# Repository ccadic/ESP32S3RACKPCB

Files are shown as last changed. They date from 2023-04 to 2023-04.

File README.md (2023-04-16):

# ESP32S3RACKPCB
This is a 1U rack PCB to hold 8 x ESP32S3 Wroom chips.

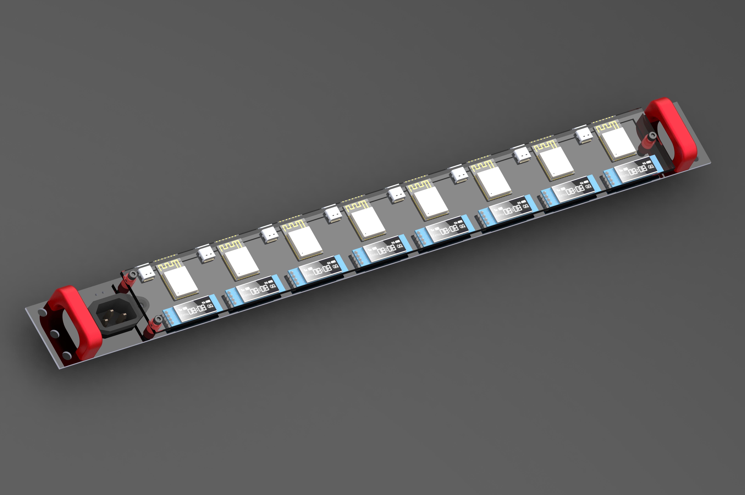
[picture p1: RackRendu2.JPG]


You have the STEP file, solidworks files, Kicad files and gerbers
@sulfuroid

My USDT address: 0xA7Cb711124e1Be5cad35aABB5d8a29b6dfdfc594 for coffees...

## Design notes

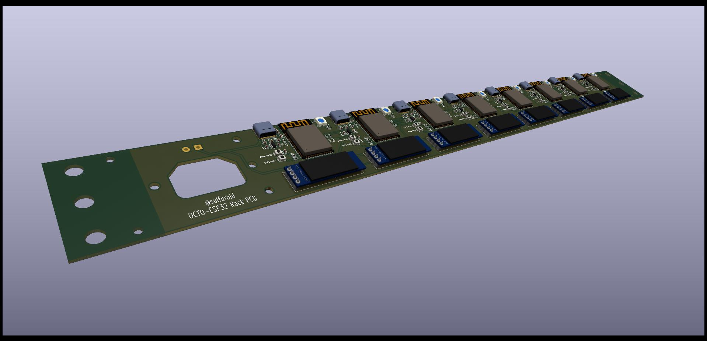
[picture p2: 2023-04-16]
RACK-ESP32S2.jpg

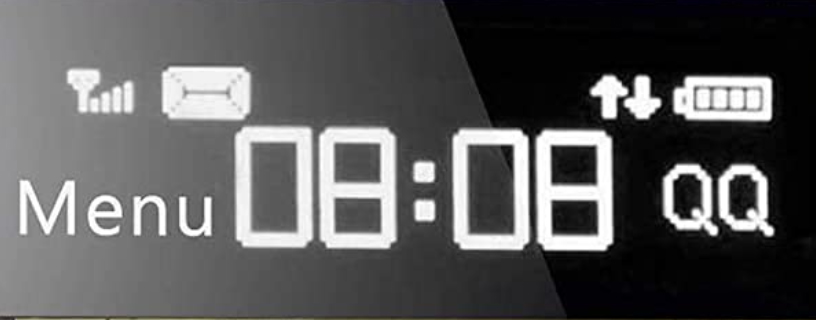
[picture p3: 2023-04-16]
displayoled.jpg

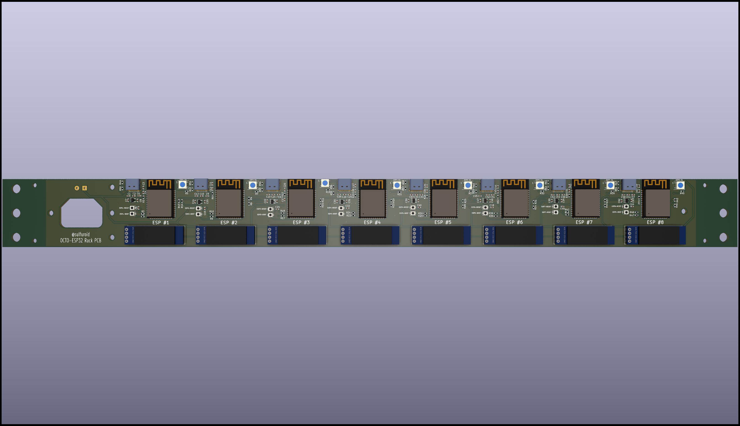
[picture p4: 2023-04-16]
RACK-ESP32S3.jpg

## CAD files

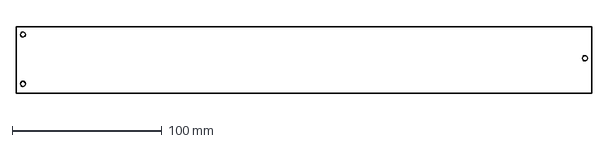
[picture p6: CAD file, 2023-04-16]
stlfiles/acrylic_front_protection.DXF
385.0 x 44.6 mm

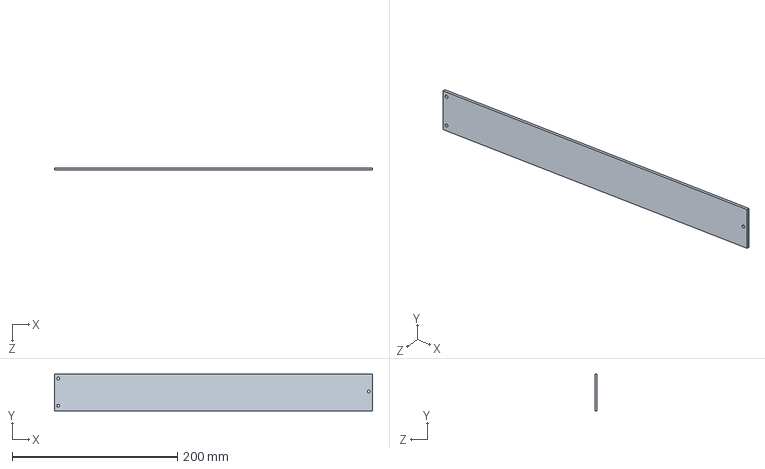
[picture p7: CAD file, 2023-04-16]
vitre.SLDPRT
385.0 x 44.6 x 3.00 mm

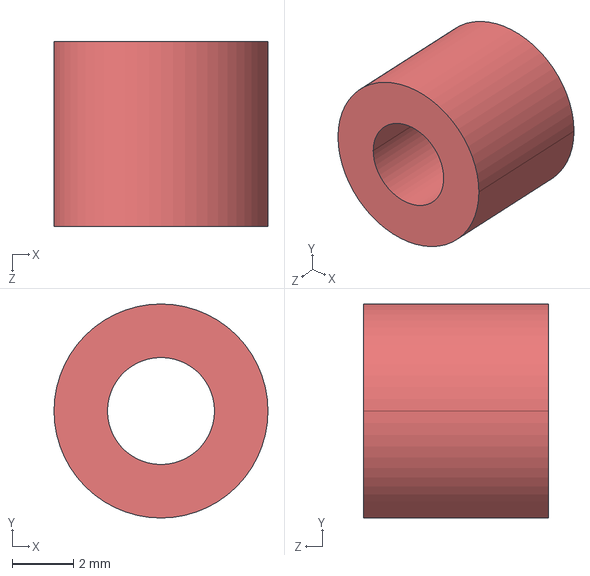
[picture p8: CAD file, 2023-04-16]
stlfiles/spacers.STEP
7.00 x 7.00 x 6.05 mm

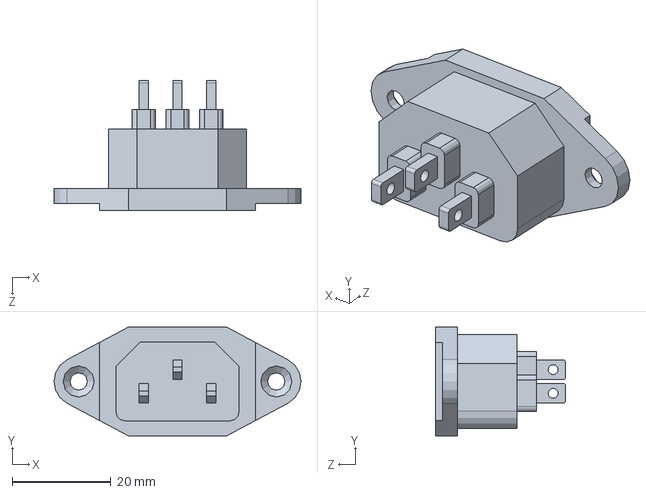
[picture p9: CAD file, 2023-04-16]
IEC-C4-3pins.SLDPRT
50.0 x 22.0 x 26.4 mm

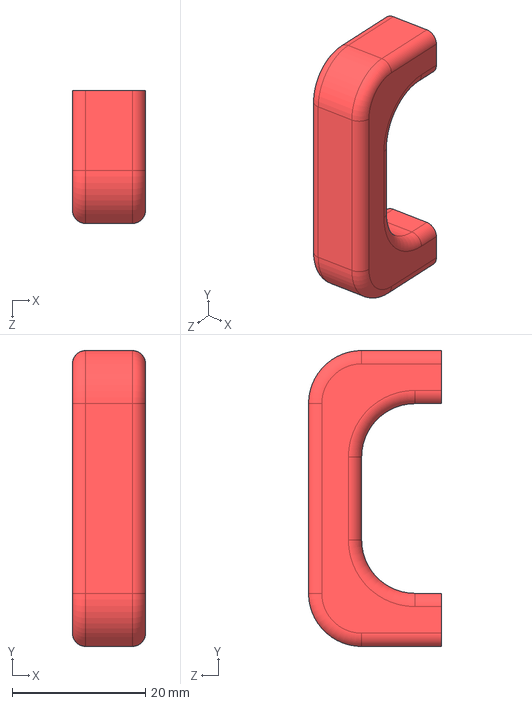
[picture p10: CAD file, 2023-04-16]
stlfiles/poignee.STEP
11.0 x 44.5 x 20.0 mm

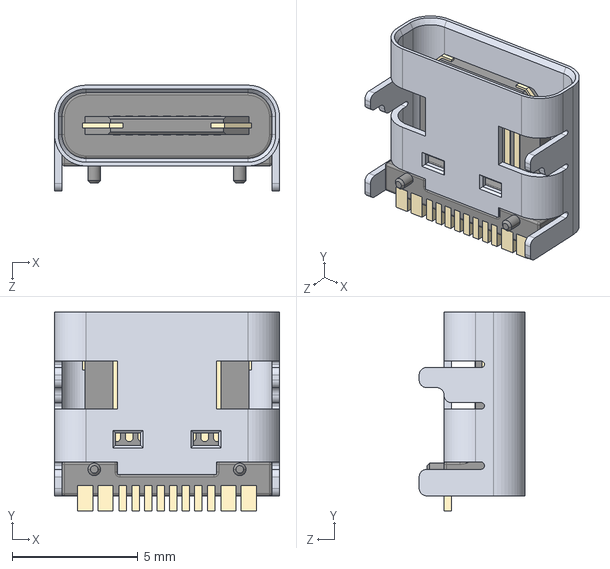
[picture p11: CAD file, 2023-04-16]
USB Type C Port (SMD Type).STEP
8.94 x 7.90 x 4.20 mm

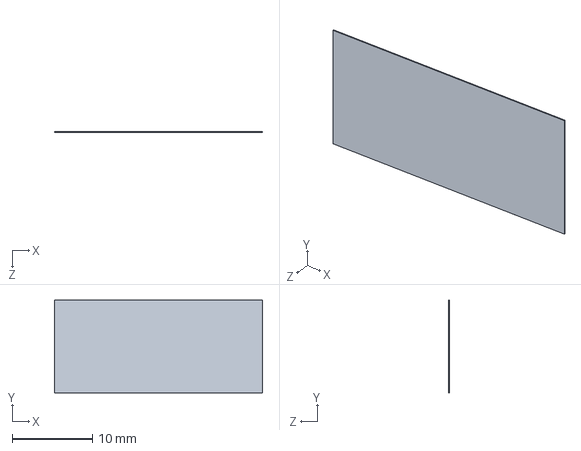
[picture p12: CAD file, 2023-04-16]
oleddisplay.SLDPRT
26.0 x 11.6 x 0.1 mm

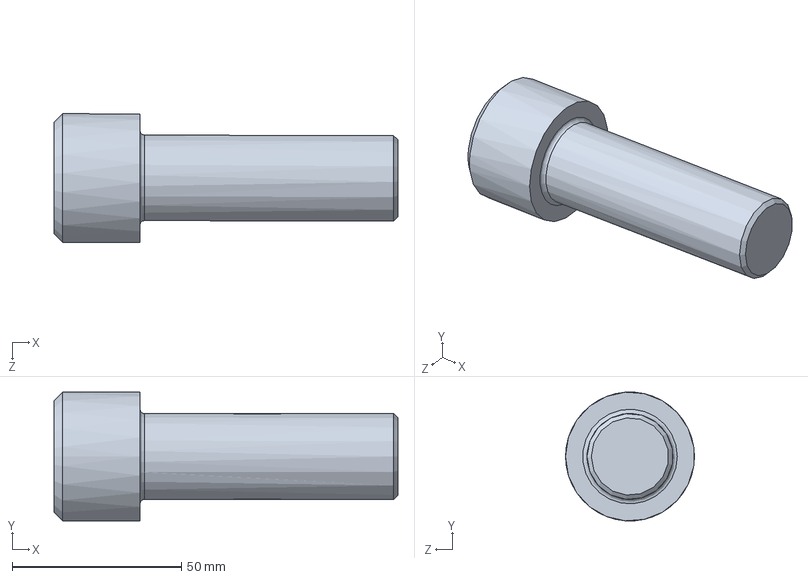
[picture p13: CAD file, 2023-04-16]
socket head cap screw_ai.SLDPRT
101.6 x 38.0 x 38.1 mm

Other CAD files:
poignee.SLDPRT
spacers.SLDPRT
stlfiles/poignee.STL
stlfiles/spacers.STL

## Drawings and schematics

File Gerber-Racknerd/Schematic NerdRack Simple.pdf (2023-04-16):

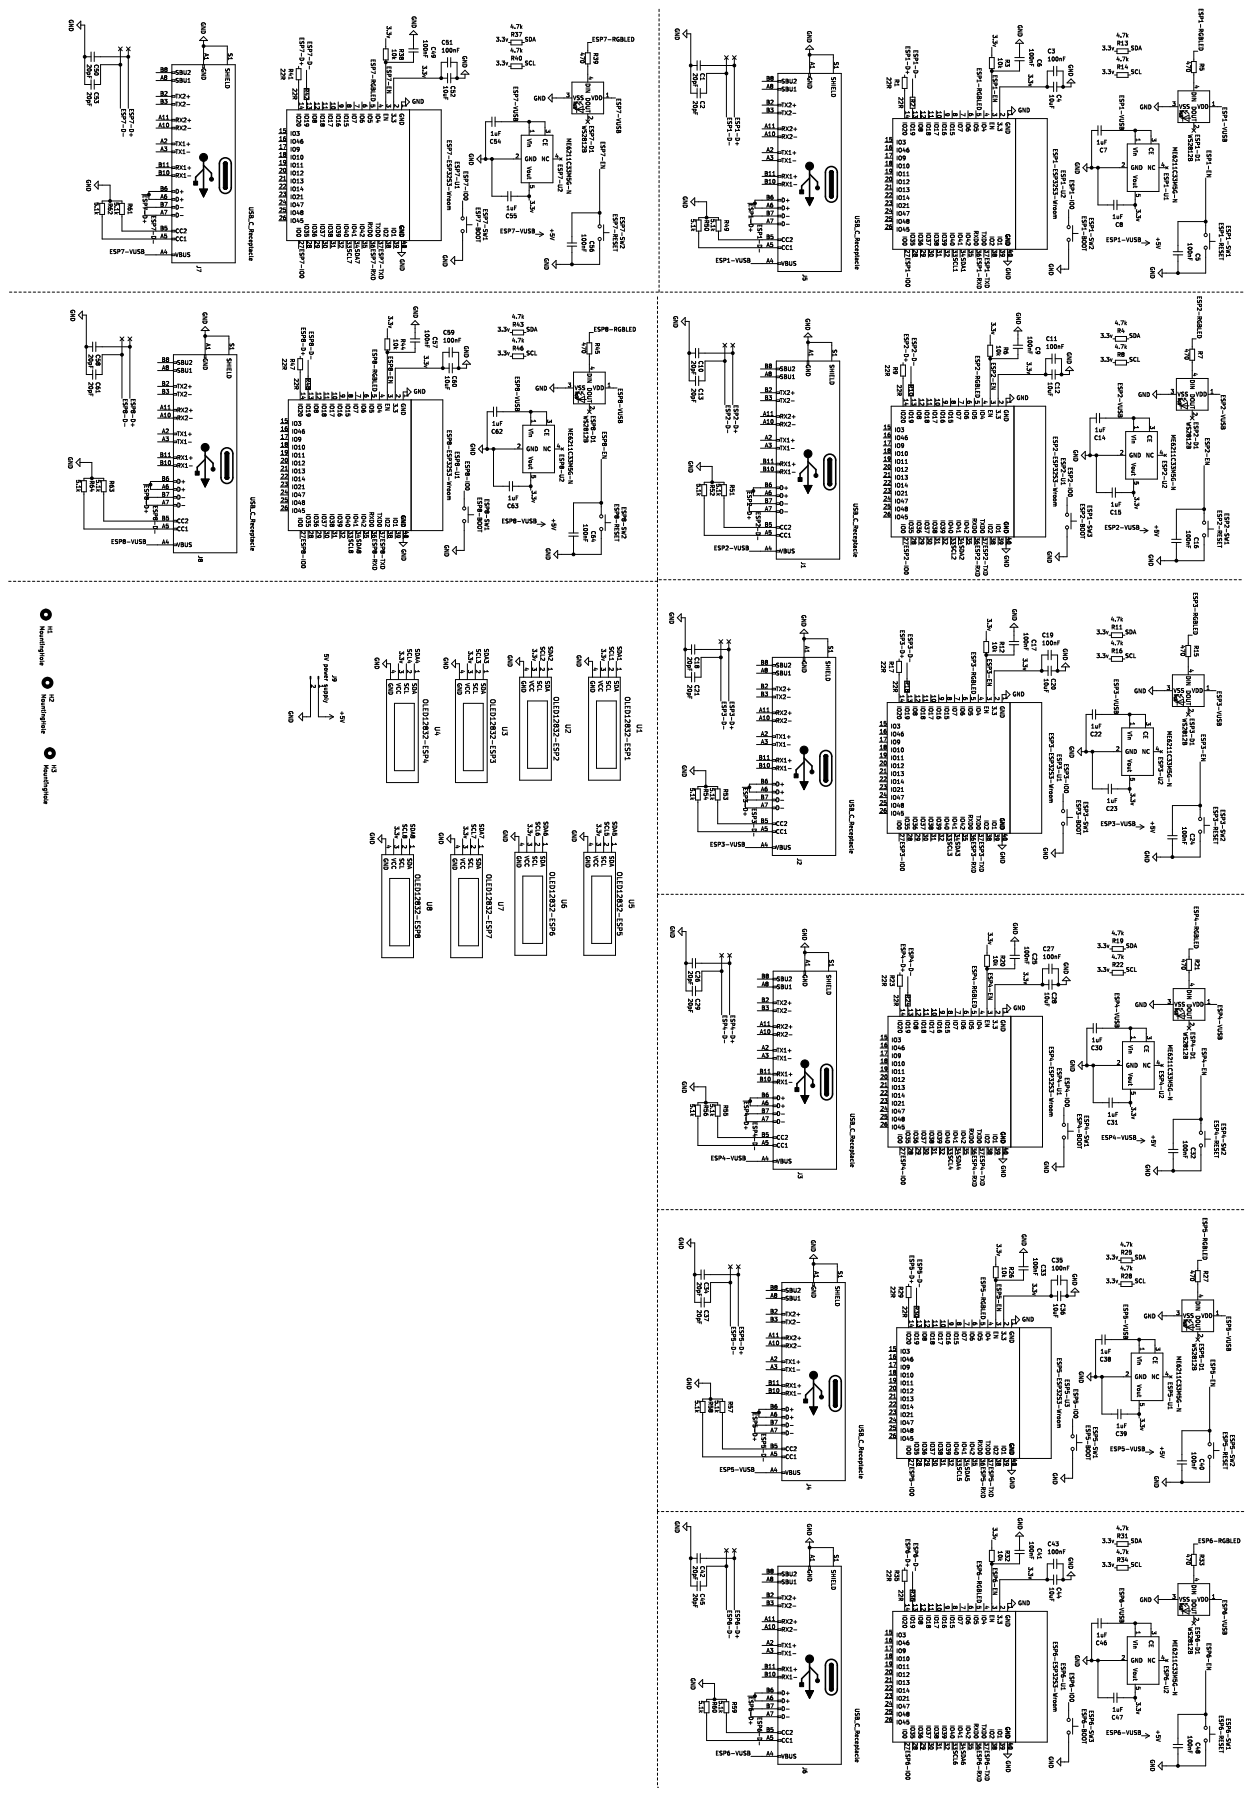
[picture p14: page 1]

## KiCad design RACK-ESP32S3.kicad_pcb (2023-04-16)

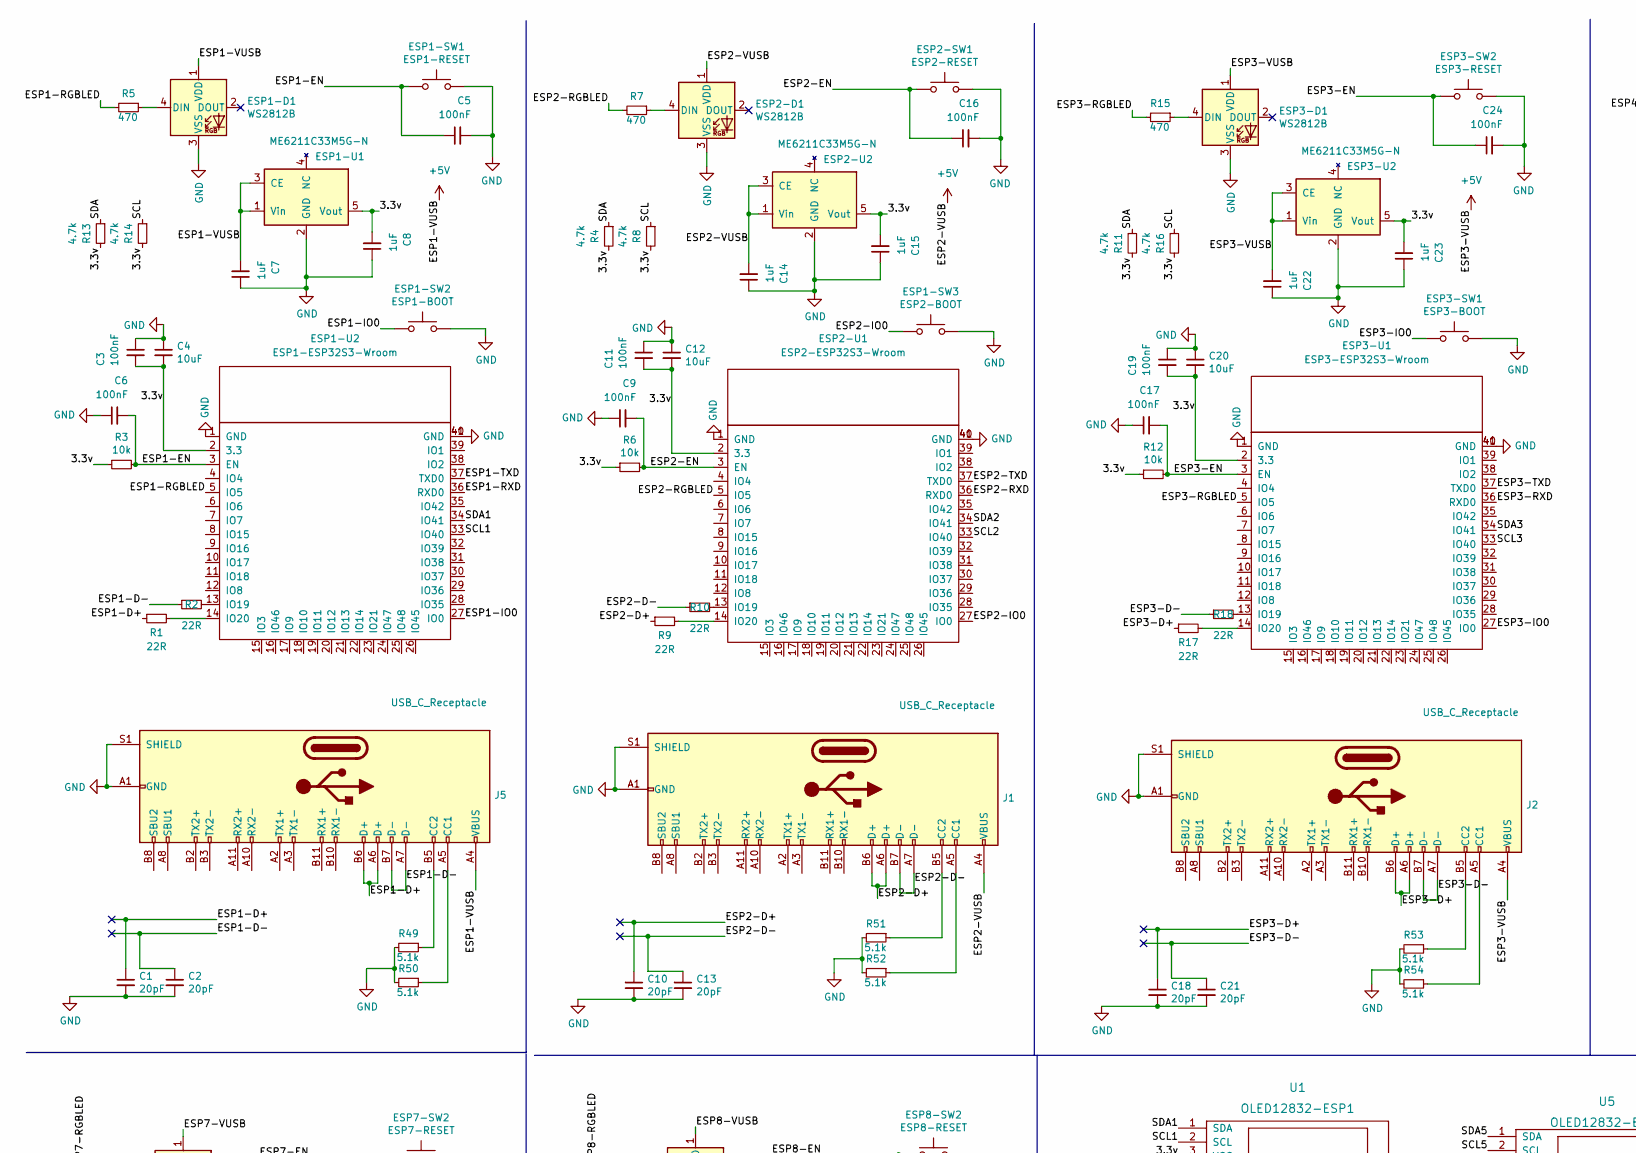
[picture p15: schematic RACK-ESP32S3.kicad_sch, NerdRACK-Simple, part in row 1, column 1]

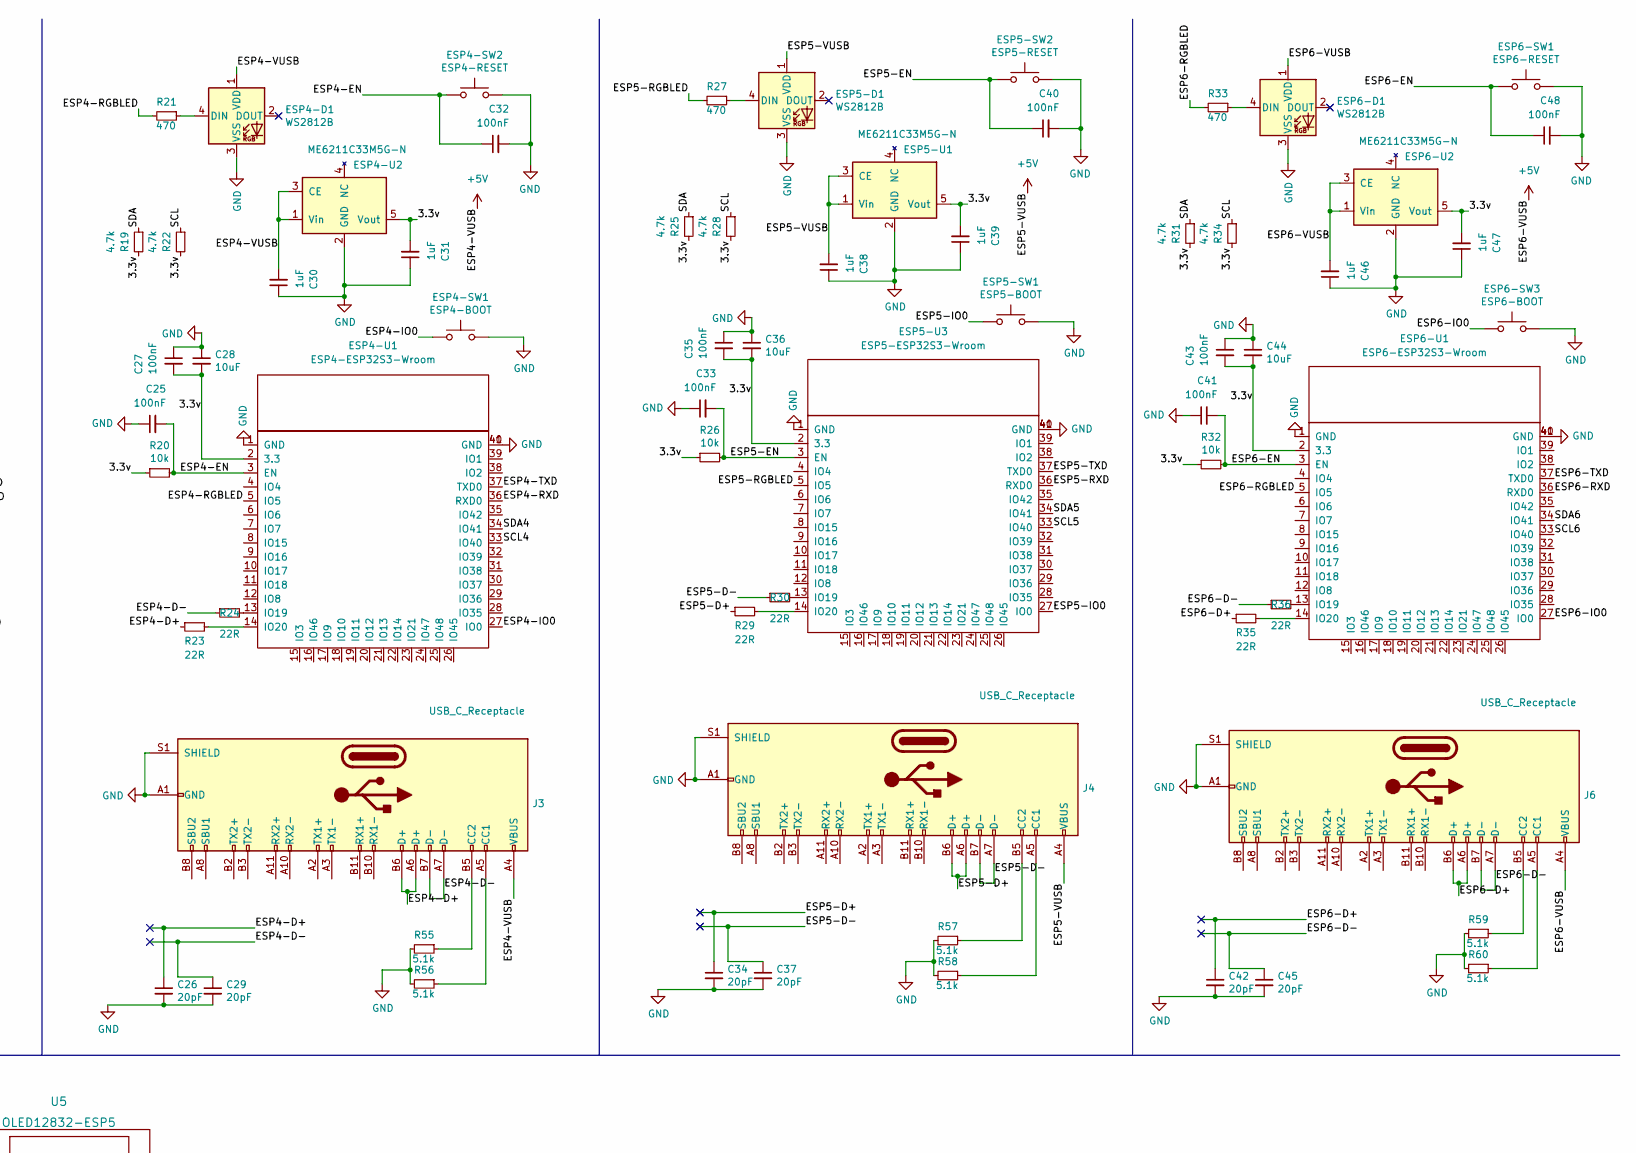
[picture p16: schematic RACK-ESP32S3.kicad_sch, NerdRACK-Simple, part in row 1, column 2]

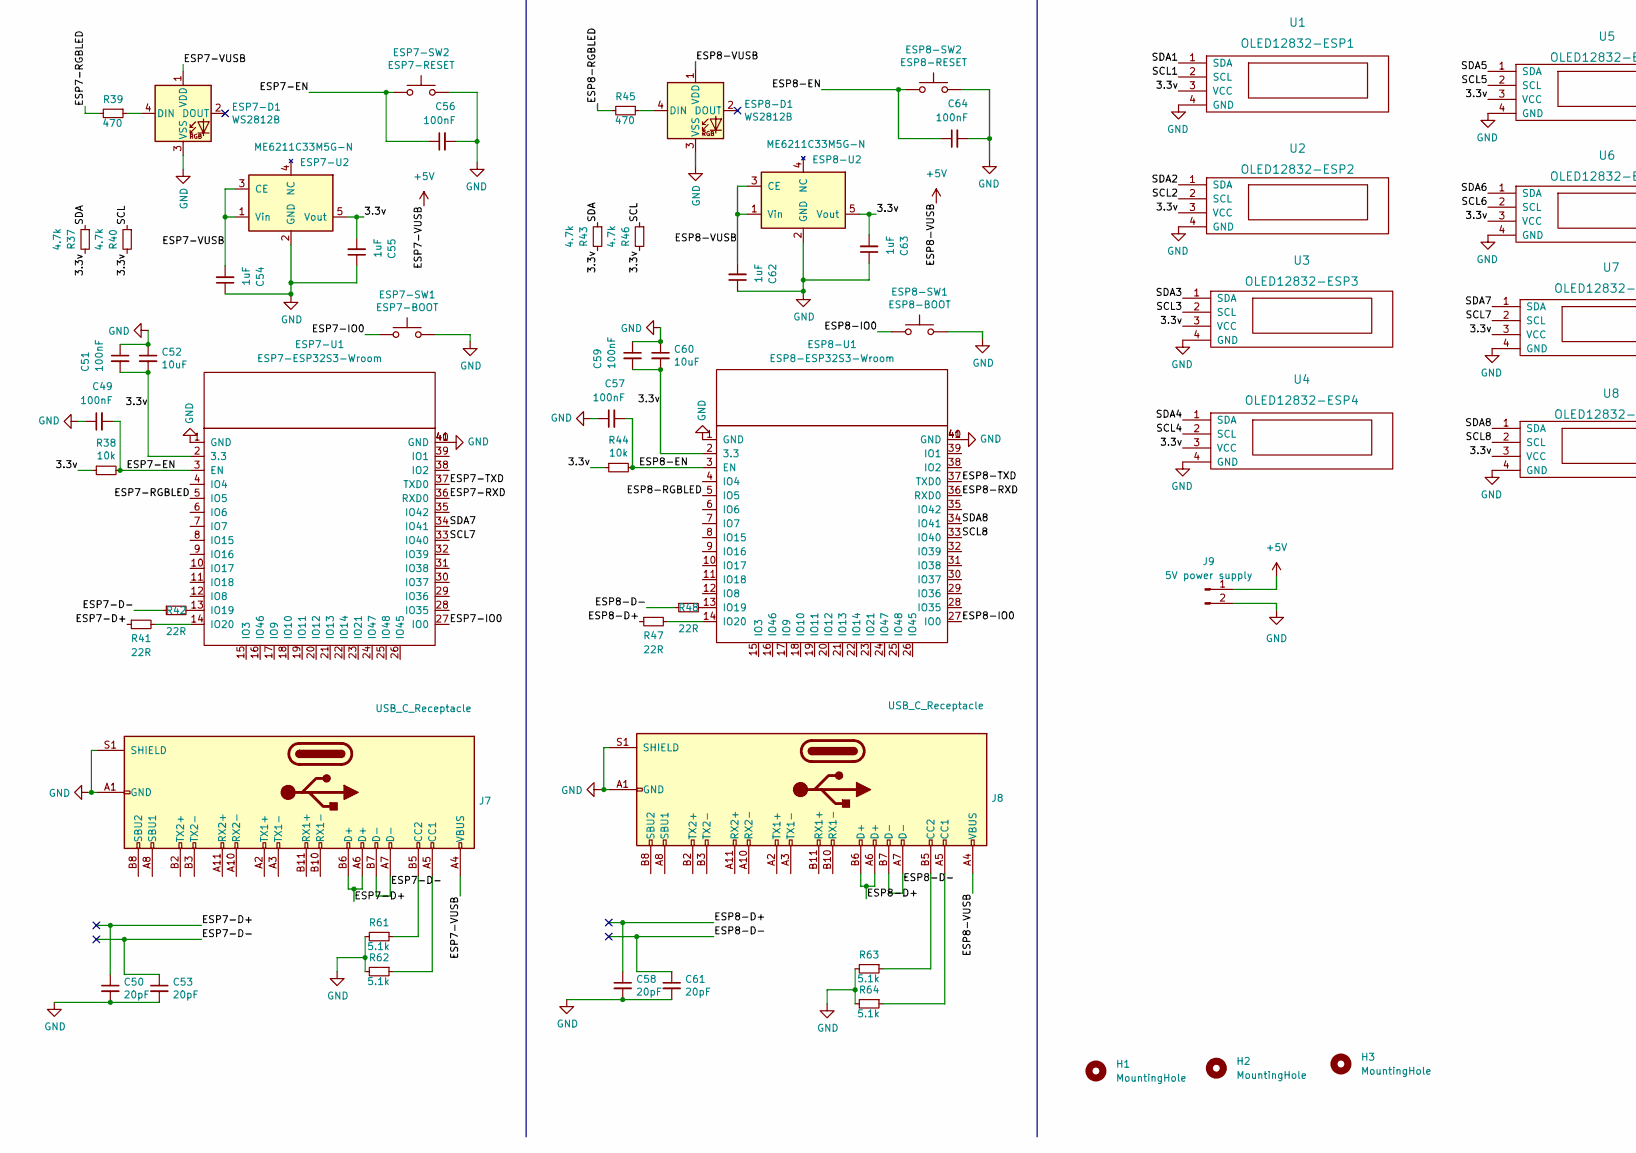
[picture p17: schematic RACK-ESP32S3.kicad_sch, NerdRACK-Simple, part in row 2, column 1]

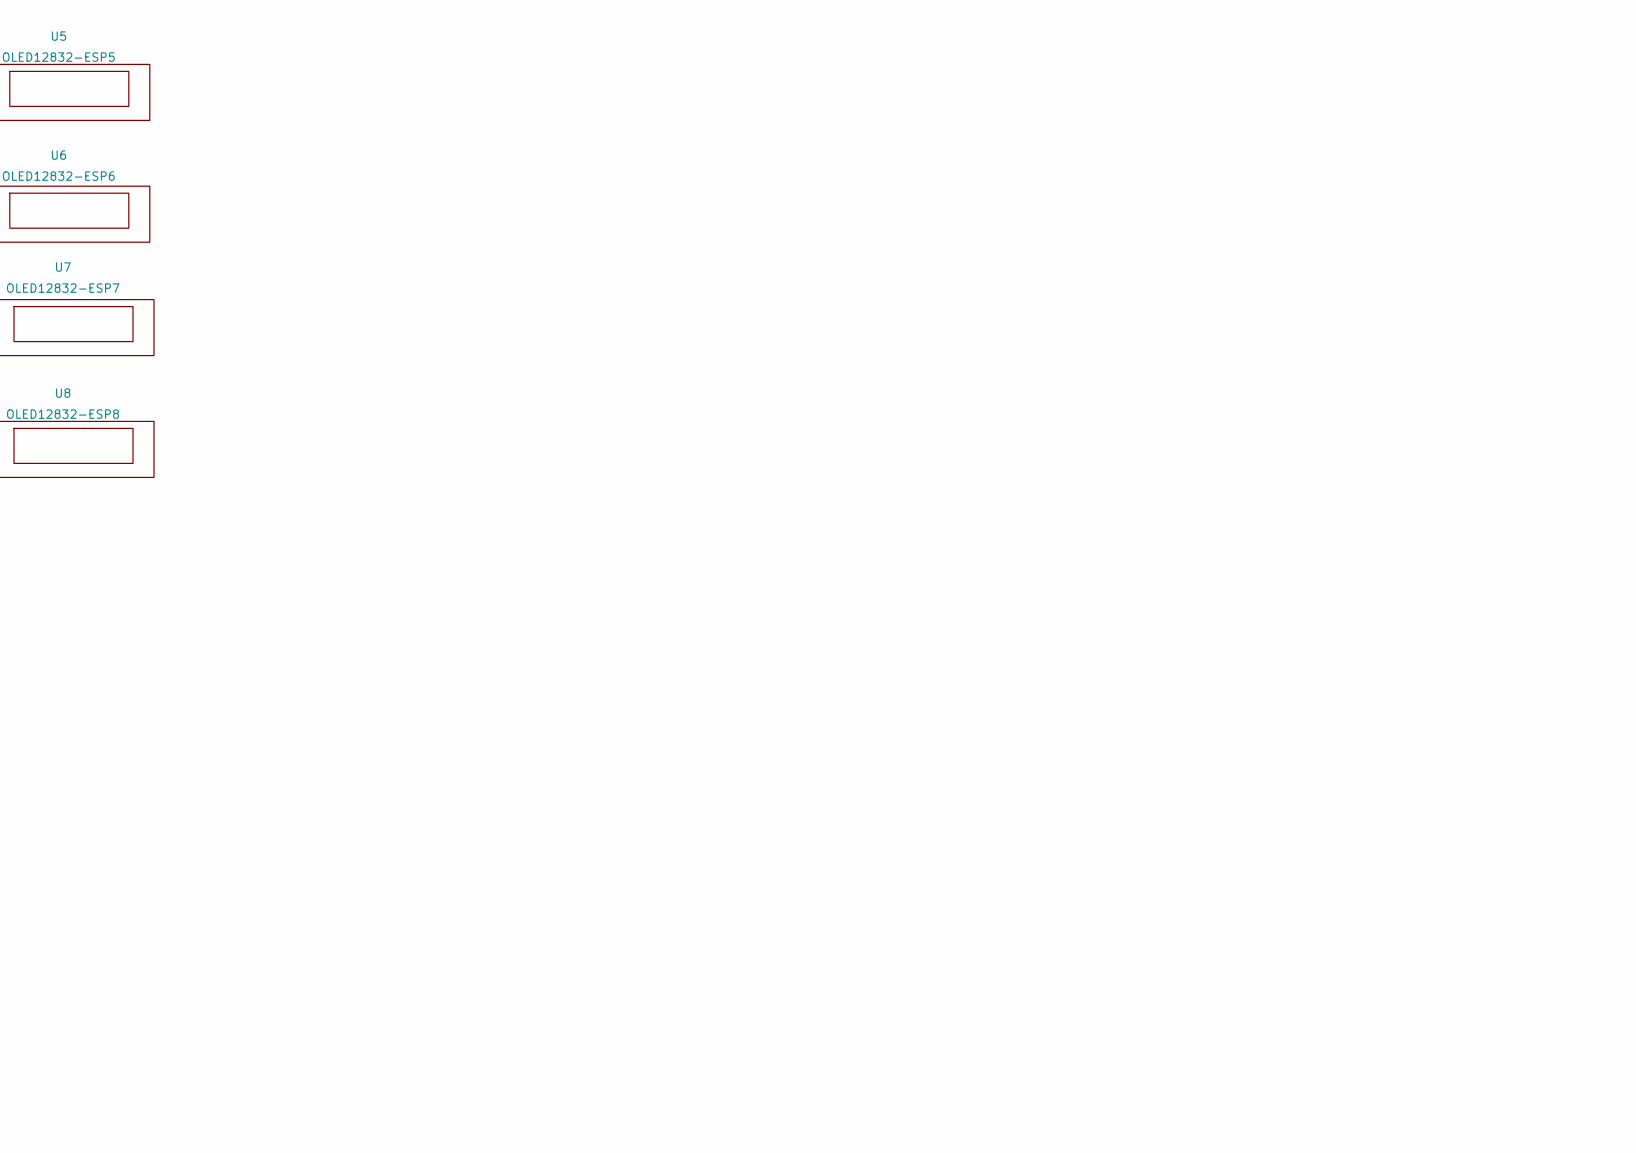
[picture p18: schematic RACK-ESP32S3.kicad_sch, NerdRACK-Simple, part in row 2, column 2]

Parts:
C1, C2, C10, C13, C18, C21, C26, C29, C34, C37, C42, C45, C50, C53, C58, C61: 20pF; C_0603_1608Metric
C3, C5, C6, C9, C11, C16, C17, C19, C24, C25, C27, C32, C33, C35, C40, C41, C43, C48, C49, C51, C56, C57, C59, C64: 100nF; C_0603_1608Metric
C4, C12, C20, C28, C36, C44, C52, C60: 10uF; C_0603_1608Metric
C7, C8, C14, C15, C22, C23, C30, C31, C38, C39, C46, C47, C54, C55, C62, C63: 1uF; C_0603_1608Metric
ESP1-D1, ESP2-D1, ESP3-D1, ESP4-D1, ESP5-D1, ESP6-D1, ESP7-D1, ESP8-D1: WS2812B; LED_WS2812B_PLCC4_5.0x5.0mm_P3.2mm
ESP1-SW1: ESP1-RESET; SW_SPST_B3U-1000P
ESP1-SW2: ESP1-BOOT; SW_SPST_B3U-1000P
ESP1-SW3: ESP2-BOOT; SW_SPST_B3U-1000P
ESP1-U1, ESP2-U2, ESP3-U2, ESP4-U2, ESP5-U1, ESP6-U2, ESP7-U2, ESP8-U2: ME6211C33M5G-N; SOT-23-5
ESP1-U2: ESP1-ESP32S3-Wroom; ESP32-S3-WROOM-1
ESP2-SW1: ESP2-RESET; SW_SPST_B3U-1000P
ESP2-U1: ESP2-ESP32S3-Wroom; ESP32-S3-WROOM-1
ESP3-SW1: ESP3-BOOT; SW_SPST_B3U-1000P
ESP3-SW2: ESP3-RESET; SW_SPST_B3U-1000P
ESP3-U1: ESP3-ESP32S3-Wroom; ESP32-S3-WROOM-1
ESP4-SW1: ESP4-BOOT; SW_SPST_B3U-1000P
ESP4-SW2: ESP4-RESET; SW_SPST_B3U-1000P
ESP4-U1: ESP4-ESP32S3-Wroom; ESP32-S3-WROOM-1
ESP5-SW1: ESP5-BOOT; SW_SPST_B3U-1000P
ESP5-SW2: ESP5-RESET; SW_SPST_B3U-1000P
ESP5-U3: ESP5-ESP32S3-Wroom; ESP32-S3-WROOM-1
ESP6-SW1: ESP6-RESET; SW_SPST_B3U-1000P
ESP6-SW3: ESP6-BOOT; SW_SPST_B3U-1000P
ESP6-U1: ESP6-ESP32S3-Wroom; ESP32-S3-WROOM-1
ESP7-SW1: ESP7-BOOT; SW_SPST_B3U-1000P
ESP7-SW2: ESP7-RESET; SW_SPST_B3U-1000P
ESP7-U1: ESP7-ESP32S3-Wroom; ESP32-S3-WROOM-1
ESP8-SW1: ESP8-BOOT; SW_SPST_B3U-1000P
ESP8-SW2: ESP8-RESET; SW_SPST_B3U-1000P
ESP8-U1: ESP8-ESP32S3-Wroom; ESP32-S3-WROOM-1
H1, H2, H3: MountingHole; MountingHole_3.5mm
J1, J2, J3, J4, J5, J6, J7, J8: USB_C_Receptacle; GT-USB-7010
J9: 5V power supply; TerminalBlock_bornier-2_P5.08mm
R1, R2, R9, R10, R17, R18, R23, R24, R29, R30, R35, R36, R41, R42, R47, R48: 22R; R_0603_1608Metric
R3, R6, R12, R20, R26, R32, R38, R44: 10k; R_0603_1608Metric
R4, R8, R11, R13, R14, R16, R19, R22, R25, R28, R31, R34, R37, R40, R43, R46: 4.7k; R_0603_1608Metric
R5, R7, R15, R21, R27, R33, R39, R45: 470; R_0603_1608Metric
R49, R50, R51, R52, R53, R54, R55, R56, R57, R58, R59, R60, R61, R62, R63, R64: 5.1k; R_0603_1608Metric
U1: OLED12832-ESP1; OLED-0.91-128x32
U2: OLED12832-ESP2; OLED-0.91-128x32
U3: OLED12832-ESP3; OLED-0.91-128x32
U4: OLED12832-ESP4; OLED-0.91-128x32
U5: OLED12832-ESP5; OLED-0.91-128x32
U6: OLED12832-ESP6; OLED-0.91-128x32
U7: OLED12832-ESP7; OLED-0.91-128x32
U8: OLED12832-ESP8; OLED-0.91-128x32

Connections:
+5V: C7.2, C14.2, C22.2, C30.2, C38.2, C46.2, C54.2, C62.2, ESP1-D1.1 (VDD), ESP1-U1.1 (Vin), ESP1-U1.3 (CE), ESP2-D1.1 (VDD), ESP2-U2.1 (Vin), ESP2-U2.3 (CE), ESP3-D1.1 (VDD), ESP3-U2.1 (Vin), ESP3-U2.3 (CE), ESP4-D1.1 (VDD), ESP4-U2.1 (Vin), ESP4-U2.3 (CE), ESP5-D1.1 (VDD), ESP5-U1.1 (Vin), ESP5-U1.3 (CE), ESP6-D1.1 (VDD), ESP6-U2.1 (Vin), ESP6-U2.3 (CE), ESP7-D1.1 (VDD), ESP7-U2.1 (Vin), ESP7-U2.3 (CE), ESP8-D1.1 (VDD), ESP8-U2.1 (Vin), ESP8-U2.3 (CE), J1.A4 (VBUS), J1.A9 (VBUS), J1.B4 (VBUS), J1.B9 (VBUS), J2.A4 (VBUS), J2.A9 (VBUS), J2.B4 (VBUS), J2.B9 (VBUS), J3.A4 (VBUS), J3.A9 (VBUS), J3.B4 (VBUS), J3.B9 (VBUS), J4.A4 (VBUS), J4.A9 (VBUS), J4.B4 (VBUS), J4.B9 (VBUS), J5.A4 (VBUS), J5.A9 (VBUS), J5.B4 (VBUS), J5.B9 (VBUS), J6.A4 (VBUS), J6.A9 (VBUS), J6.B4 (VBUS), J6.B9 (VBUS), J7.A4 (VBUS), J7.A9 (VBUS), J7.B4 (VBUS), J7.B9 (VBUS), J8.A4 (VBUS), J8.A9 (VBUS), J8.B4 (VBUS), J8.B9 (VBUS), J9.1
/3.3v: C3.2, C4.2, C8.2, C11.2, C12.2, C15.2, C19.2, C20.2, C23.2, C27.2, C28.2, C31.2, C35.2, C36.2, C39.2, C43.2, C44.2, C47.2, C51.2, C52.2, C55.2, C59.2, C60.2, C63.2, ESP1-U1.5 (Vout), ESP1-U2.2 (3.3), ESP2-U1.2 (3.3), ESP2-U2.5 (Vout), ESP3-U1.2 (3.3), ESP3-U2.5 (Vout), ESP4-U1.2 (3.3), ESP4-U2.5 (Vout), ESP5-U1.5 (Vout), ESP5-U3.2 (3.3), ESP6-U1.2 (3.3), ESP6-U2.5 (Vout), ESP7-U1.2 (3.3), ESP7-U2.5 (Vout), ESP8-U1.2 (3.3), ESP8-U2.5 (Vout), R3.1, R4.2, R6.1, R8.2, R11.2, R12.1, R13.2, R14.2, R16.2, R19.2, R20.1, R22.2, R25.2, R26.1, R28.2, R31.2, R32.1, R34.2, R37.2, R38.1, R40.2, R43.2, R44.1, R46.2, U1.3 (VCC), U2.3 (VCC), U3.3 (VCC), U4.3 (VCC), U5.3 (VCC), U6.3 (VCC), U7.3 (VCC), U8.3 (VCC); also elsewhere on the board
/ESP1-D+: C1.1, J5.A6 (D+), J5.B6 (D+), R1.1
/ESP1-D-: C2.1, J5.A7 (D-), J5.B7 (D-), R2.1
/ESP1-EN: C5.1, C6.2, ESP1-SW1.2, ESP1-U2.3 (EN), R3.2
/ESP1-IO0: ESP1-SW2.1, ESP1-U2.27 (IO0)
/ESP1-RGBLED: ESP1-U2.5 (IO5), R5.2
/ESP1-RXD: ESP1-U2.36 (RXD0)
/ESP1-TXD: ESP1-U2.37 (TXD0)
/ESP2-D+: C10.1, J1.A6 (D+), J1.B6 (D+), R9.1
/ESP2-D-: C13.1, J1.A7 (D-), J1.B7 (D-), R10.1
/ESP2-EN: C9.2, C16.1, ESP2-SW1.2, ESP2-U1.3 (EN), R6.2
/ESP2-IO0: ESP1-SW3.1, ESP2-U1.27 (IO0)
/ESP2-RGBLED: ESP2-U1.5 (IO5), R7.2
/ESP2-RXD: ESP2-U1.36 (RXD0)
/ESP2-TXD: ESP2-U1.37 (TXD0)
/ESP3-D+: C18.1, J2.A6 (D+), J2.B6 (D+), R17.1
/ESP3-D-: C21.1, J2.A7 (D-), J2.B7 (D-), R18.1
/ESP3-EN: C17.2, C24.1, ESP3-SW2.2, ESP3-U1.3 (EN), R12.2
/ESP3-IO0: ESP3-SW1.1, ESP3-U1.27 (IO0)
/ESP3-RGBLED: ESP3-U1.5 (IO5), R15.2
/ESP3-RXD: ESP3-U1.36 (RXD0)
/ESP3-TXD: ESP3-U1.37 (TXD0)
/ESP4-D+: C26.1, J3.A6 (D+), J3.B6 (D+), R23.1
/ESP4-D-: C29.1, J3.A7 (D-), J3.B7 (D-), R24.1
/ESP4-EN: C25.2, C32.1, ESP4-SW2.2, ESP4-U1.3 (EN), R20.2
/ESP4-IO0: ESP4-SW1.1, ESP4-U1.27 (IO0)
/ESP4-RGBLED: ESP4-U1.5 (IO5), R21.2
/ESP4-RXD: ESP4-U1.36 (RXD0)
/ESP4-TXD: ESP4-U1.37 (TXD0)
/ESP5-D+: C34.1, J4.A6 (D+), J4.B6 (D+), R29.1
/ESP5-D-: C37.1, J4.A7 (D-), J4.B7 (D-), R30.1
/ESP5-EN: C33.2, C40.1, ESP5-SW2.2, ESP5-U3.3 (EN), R26.2
/ESP5-IO0: ESP5-SW1.1, ESP5-U3.27 (IO0)
/ESP5-RGBLED: ESP5-U3.5 (IO5), R27.2
/ESP5-RXD: ESP5-U3.36 (RXD0)
/ESP5-TXD: ESP5-U3.37 (TXD0)
/ESP6-D+: C42.1, J6.A6 (D+), J6.B6 (D+), R35.1
/ESP6-D-: C45.1, J6.A7 (D-), J6.B7 (D-), R36.1
/ESP6-EN: C41.2, C48.1, ESP6-SW1.2, ESP6-U1.3 (EN), R32.2; also elsewhere on the board
/ESP6-IO0: ESP6-SW3.1, ESP6-U1.27 (IO0); also elsewhere on the board
/ESP6-RGBLED: ESP6-U1.5 (IO5), R33.2; also elsewhere on the board
/ESP7-D+: C50.1, J7.A6 (D+), J7.B6 (D+), R41.1
/ESP7-D-: C53.1, J7.A7 (D-), J7.B7 (D-), R42.1
/ESP7-EN: C49.2, C56.1, ESP7-SW2.2, ESP7-U1.3 (EN), R38.2
/ESP7-IO0: ESP7-SW1.1, ESP7-U1.27 (IO0)
/ESP7-RGBLED: ESP7-U1.5 (IO5), R39.2
/ESP7-RXD: ESP7-U1.36 (RXD0)
/ESP7-TXD: ESP7-U1.37 (TXD0)
/ESP8-D+: C58.1, J8.A6 (D+), J8.B6 (D+), R47.1
/ESP8-D-: C61.1, J8.A7 (D-), J8.B7 (D-), R48.1
/ESP8-EN: C57.2, C64.1, ESP8-SW2.2, ESP8-U1.3 (EN), R44.2
/ESP8-IO0: ESP8-SW1.1, ESP8-U1.27 (IO0)
/ESP8-RGBLED: ESP8-U1.5 (IO5), R45.2
/ESP8-RXD: ESP8-U1.36 (RXD0)
/ESP8-TXD: ESP8-U1.37 (TXD0)
/SCL: R8.1, R14.1, R16.1, R22.1, R28.1, R34.1, R40.1, R46.1
/SCL1: ESP1-U2.33 (IO40), U1.2 (SCL)
/SCL2: ESP2-U1.33 (IO40), U2.2 (SCL)
/SCL3: ESP3-U1.33 (IO40), U3.2 (SCL)
/SCL4: ESP4-U1.33 (IO40), U4.2 (SCL)
/SCL5: ESP5-U3.33 (IO40), U5.2 (SCL)
/SCL6: ESP6-U1.33 (IO40), U6.2 (SCL); also elsewhere on the board
/SCL7: ESP7-U1.33 (IO40), U7.2 (SCL)
/SCL8: ESP8-U1.33 (IO40), U8.2 (SCL)
/SDA: R4.1, R11.1, R13.1, R19.1, R25.1, R31.1, R37.1, R43.1
/SDA1: ESP1-U2.34 (IO41), U1.1 (SDA)
/SDA2: ESP2-U1.34 (IO41), U2.1 (SDA)
/SDA3: ESP3-U1.34 (IO41), U3.1 (SDA)
/SDA4: ESP4-U1.34 (IO41), U4.1 (SDA)
/SDA5: ESP5-U3.34 (IO41), U5.1 (SDA)
/SDA6: ESP6-U1.34 (IO41), U6.1 (SDA); also elsewhere on the board
/SDA7: ESP7-U1.34 (IO41), U7.1 (SDA)
/SDA8: ESP8-U1.34 (IO41), U8.1 (SDA)
GND: C1.2, C2.2, C3.1, C4.1, C5.2, C6.1, C7.1, C8.1, C9.1, C10.2, C11.1, C12.1, C13.2, C14.1, C15.1, C16.2, C17.1, C18.2, C19.1, C20.1, C21.2, C22.1, C23.1, C24.2, C25.1, C26.2, C27.1, C28.1, C29.2, C30.1, C31.1, C32.2, C33.1, C34.2, C35.1, C36.1, C37.2, C38.1, C39.1, C40.2, C41.1, C42.2, C43.1, C44.1, C45.2, C46.1, C47.1, C48.2, C49.1, C50.2, C51.1, C52.1, C53.2, C54.1, C55.1, C56.2, C57.1, C58.2, C59.1, C60.1, C61.2, C62.1, C63.1, C64.2, ESP1-D1.3 (VSS), ESP1-SW1.1, ESP1-SW2.2, ESP1-SW3.2, ESP1-U1.2 (GND), ESP1-U2.1 (GND), ESP1-U2.40 (GND), ESP1-U2.41 (GND), ESP2-D1.3 (VSS), ESP2-SW1.1, ESP2-U1.1 (GND), ESP2-U1.40 (GND), ESP2-U1.41 (GND), ESP2-U2.2 (GND), ESP3-D1.3 (VSS), ESP3-SW1.2, ESP3-SW2.1, ESP3-U1.1 (GND), ESP3-U1.40 (GND), ESP3-U1.41 (GND), ESP3-U2.2 (GND), ESP4-D1.3 (VSS), ESP4-SW1.2, ESP4-SW2.1, ESP4-U1.1 (GND), ESP4-U1.40 (GND), ESP4-U1.41 (GND), ESP4-U2.2 (GND), ESP5-D1.3 (VSS), ESP5-SW1.2, ESP5-SW2.1, ESP5-U1.2 (GND), ESP5-U3.1 (GND), ESP5-U3.40 (GND), ESP5-U3.41 (GND), ESP6-D1.3 (VSS), ESP6-SW1.1, ESP6-SW3.2, ESP6-U1.1 (GND), ESP6-U1.40 (GND), ESP6-U1.41 (GND), ESP6-U2.2 (GND), ESP7-D1.3 (VSS), ESP7-SW1.2, ESP7-SW2.1, ESP7-U1.1 (GND), ESP7-U1.40 (GND), ESP7-U1.41 (GND), ESP7-U2.2 (GND), ESP8-D1.3 (VSS), ESP8-SW1.2, ESP8-SW2.1, ESP8-U1.1 (GND), ESP8-U1.40 (GND), ESP8-U1.41 (GND), ESP8-U2.2 (GND), J1.A1 (GND), J1.A12 (GND), J1.B1 (GND), J1.B12 (GND), J1.S1 (SHIELD), J2.A1 (GND), J2.A12 (GND), J2.B1 (GND), J2.B12 (GND), J2.S1 (SHIELD), J3.A1 (GND), J3.A12 (GND), J3.B1 (GND), J3.B12 (GND), J3.S1 (SHIELD), J4.A1 (GND), J4.A12 (GND), J4.B1 (GND), J4.B12 (GND), J4.S1 (SHIELD), J5.A1 (GND), J5.A12 (GND), J5.B1 (GND), J5.B12 (GND), J5.S1 (SHIELD), J6.A1 (GND), J6.A12 (GND), J6.B1 (GND), J6.B12 (GND), J6.S1 (SHIELD), J7.A1 (GND), J7.A12 (GND), J7.B1 (GND), J7.B12 (GND), J7.S1 (SHIELD), J8.A1 (GND), J8.A12 (GND), J8.B1 (GND), J8.B12 (GND), J8.S1 (SHIELD), J9.2, R49.2, R50.2, R51.2, R52.2, R53.2, R54.2, R55.2, R56.2, R57.2, R58.2, R59.2, R60.2, R61.2, R62.2, R63.2, R64.2, U1.4 (GND), U2.4 (GND), U3.4 (GND), U4.4 (GND), U5.4 (GND), U6.4 (GND), U7.4 (GND), U8.4 (GND); also elsewhere on the board
unnamed: ESP1-D1.4 (DIN), R5.1
unnamed: ESP1-U2.13 (IO19), R2.2
unnamed: ESP1-U2.14 (IO20), R1.2
unnamed: ESP2-D1.4 (DIN), R7.1
unnamed: ESP2-U1.13 (IO19), R10.2
unnamed: ESP2-U1.14 (IO20), R9.2
unnamed: ESP3-D1.4 (DIN), R15.1
unnamed: ESP3-U1.13 (IO19), R18.2
unnamed: ESP3-U1.14 (IO20), R17.2
unnamed: ESP4-D1.4 (DIN), R21.1
unnamed: ESP4-U1.13 (IO19), R24.2
unnamed: ESP4-U1.14 (IO20), R23.2
unnamed: ESP5-D1.4 (DIN), R27.1
unnamed: ESP5-U3.13 (IO19), R30.2
unnamed: ESP5-U3.14 (IO20), R29.2
unnamed: ESP6-D1.4 (DIN), R33.1
unnamed 93: ESP6-U1.13 (IO19), R36.2; also elsewhere on the board
unnamed 94: ESP6-U1.14 (IO20), R35.2; also elsewhere on the board
unnamed: ESP7-D1.4 (DIN), R39.1
unnamed: ESP7-U1.13 (IO19), R42.2
unnamed: ESP7-U1.14 (IO20), R41.2
unnamed: ESP8-D1.4 (DIN), R45.1
unnamed: ESP8-U1.13 (IO19), R48.2
unnamed: ESP8-U1.14 (IO20), R47.2
unnamed: J1.A5 (CC1), R52.1
unnamed: J1.B5 (CC2), R51.1
unnamed: J2.A5 (CC1), R54.1
unnamed: J2.B5 (CC2), R53.1
unnamed: J3.A5 (CC1), R56.1
unnamed: J3.B5 (CC2), R55.1
unnamed: J4.A5 (CC1), R58.1
unnamed: J4.B5 (CC2), R57.1
unnamed: J5.A5 (CC1), R50.1
unnamed: J5.B5 (CC2), R49.1
unnamed: J6.A5 (CC1), R60.1
unnamed: J6.B5 (CC2), R59.1
unnamed: J7.A5 (CC1), R62.1
unnamed: J7.B5 (CC2), R61.1
unnamed: J8.A5 (CC1), R64.1
unnamed: J8.B5 (CC2), R63.1

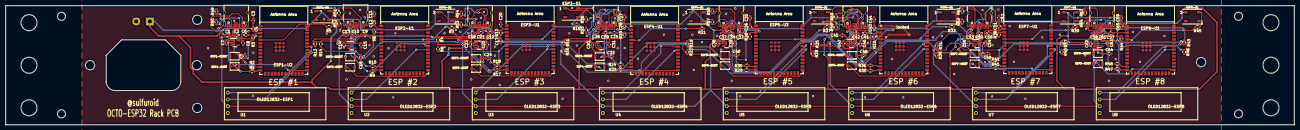
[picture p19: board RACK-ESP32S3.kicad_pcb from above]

Board: 2 copper layers, 482.6 x 44.6 mm, 188 parts (1 on the bottom side), 101 nets.

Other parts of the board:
locked: ESP6-ESP32S3-Wroom; ESP32-S3-WROOM-1

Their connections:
/3.3v: locked.2 (3.3); also elsewhere on the board
/ESP6-EN: locked.3 (EN); also elsewhere on the board
/ESP6-IO0: locked.27 (IO0); also elsewhere on the board
/ESP6-RGBLED: locked.5 (IO5); also elsewhere on the board
/SCL6: locked.33 (IO40); also elsewhere on the board
/SDA6: locked.34 (IO41); also elsewhere on the board
GND: locked.1 (GND), locked.40 (GND), locked.41 (GND); also elsewhere on the board
unnamed 93: locked.13 (IO19); also elsewhere on the board
unnamed 94: locked.14 (IO20); also elsewhere on the board
